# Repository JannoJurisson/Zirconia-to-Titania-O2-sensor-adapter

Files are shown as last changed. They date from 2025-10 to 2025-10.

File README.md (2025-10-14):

# Zirconia-to-Titania-O2-sensor-adapter
Adaper to translate a zirconia oxygen sensor voltage output (0-1V) to titania sensor signal (resistance or 0-5V)

Lambda_translator_top_no_screen

Lambda_translator_top_w_screen

Lambda_translator_bottom

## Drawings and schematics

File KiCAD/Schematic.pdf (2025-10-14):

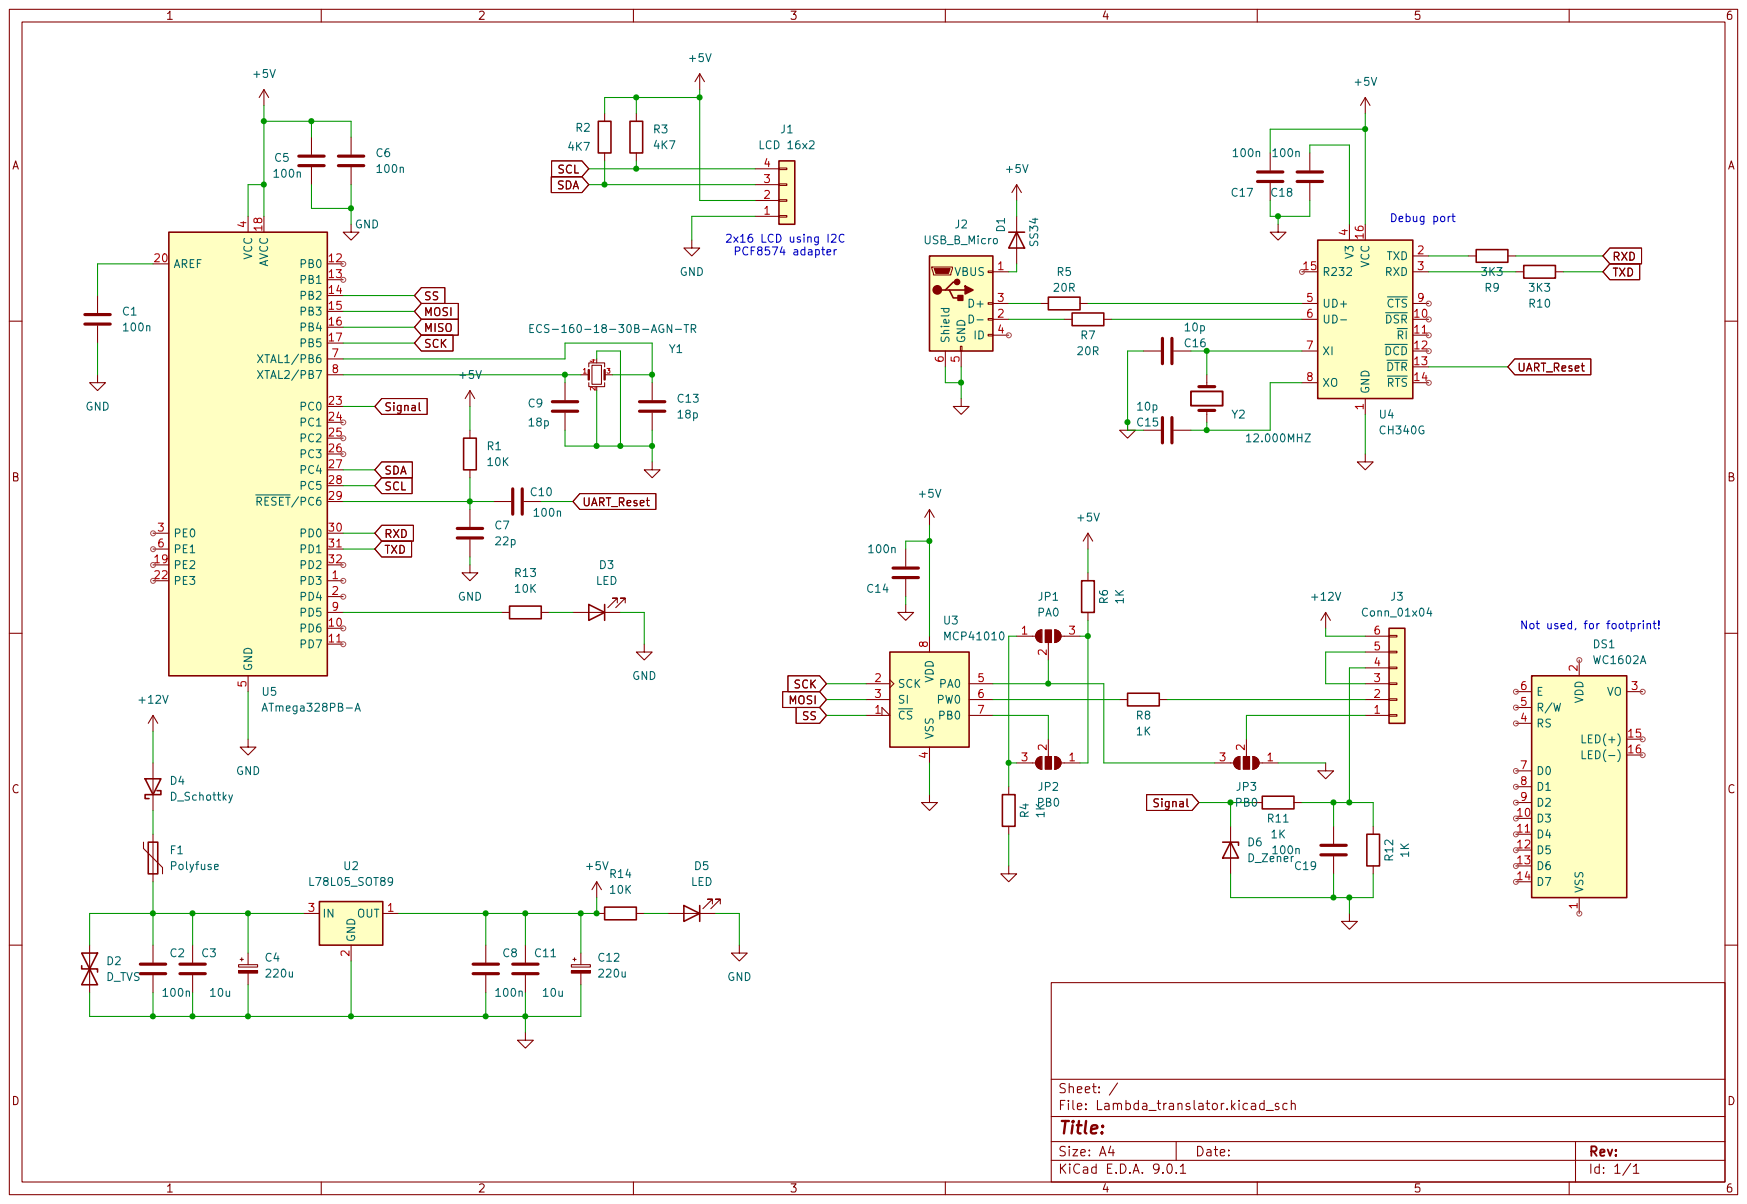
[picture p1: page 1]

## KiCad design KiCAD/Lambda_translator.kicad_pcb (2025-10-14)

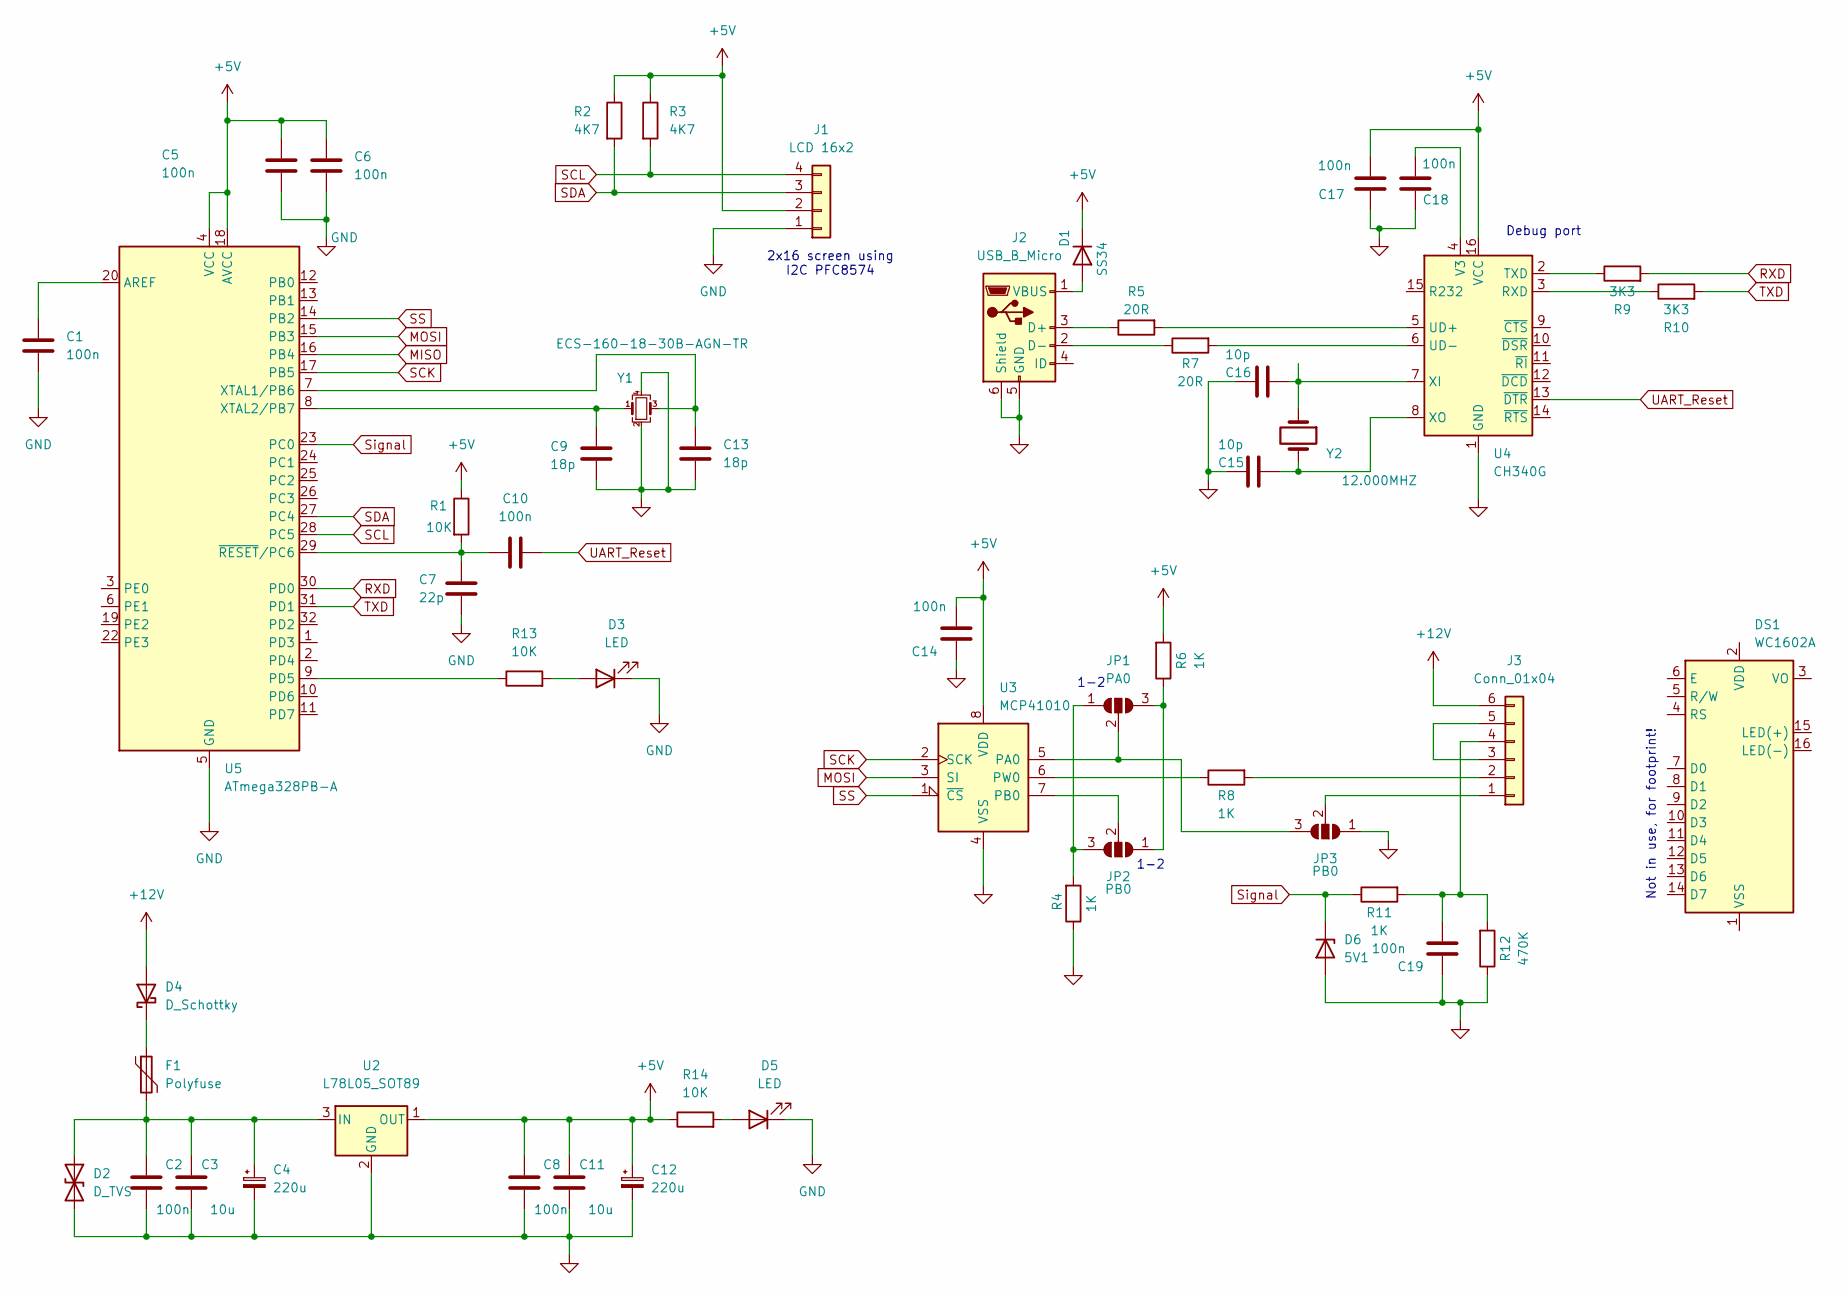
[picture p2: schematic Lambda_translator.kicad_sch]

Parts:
C1: 100n; R_0603_1608Metric
C2, C8, C14, C17, C18, C19: 100n; C_0603_1608Metric_Pad1.08x0.95mm_HandSolder
C3, C11: 10u; C_1206_3216Metric_Pad1.33x1.80mm_HandSolder
C4: 220u; CP_Elec_10x10
C5, C6, C10: 100n; C_0603_1608Metric
C7: 22p; C_0603_1608Metric
C9, C13: 18p; C_0805_2012Metric
C12: 220u; CP_Elec_6.3x5.9
C15, C16: 10p; C_0603_1608Metric_Pad1.08x0.95mm_HandSolder
D1: SS34; D_SMA
D2: D_TVS; D_SMA
D3, D5: LED; LED_1206_3216Metric
D4: D_Schottky; D_SMA
D6: 5V1; D_MiniMELF
DS1: WC1602A
F1: Polyfuse; R_2512_6332Metric
J1: LCD 16x2; PinHeader_1x04_P2.54mm_Vertical
J2: USB_B_Micro; USB_Micro-B_Molex_47346-0001
J3: Conn_01x04; PhoenixContact_MC_1,5_6-G-5.08_1x06_P5.08mm_Horizontal
JP1: PA0; SolderJumper-3_P1.3mm_Open_RoundedPad1.0x1.5mm
JP2, JP3: PB0; SolderJumper-3_P1.3mm_Open_RoundedPad1.0x1.5mm
R1, R13, R14: 10K; R_0603_1608Metric
R2, R3: 4K7; R_0603_1608Metric
R4, R6, R8, R11: 1K; R_0603_1608Metric_Pad0.98x0.95mm_HandSolder
R5, R7: 20R; R_0603_1608Metric_Pad0.98x0.95mm_HandSolder
R9, R10: 3K3; R_0603_1608Metric_Pad0.98x0.95mm_HandSolder
R12: 470K; R_0603_1608Metric_Pad0.98x0.95mm_HandSolder
U2: L78L05_SOT89; SOT-89-3
U3: MCP41010; SOIC-8_3.9x4.9mm_P1.27mm
U4: CH340G; SOIC-16_3.9x9.9mm_P1.27mm
U5: ATmega328PB-A; TQFP-32_7x7mm_P0.8mm
Y1: ECS-160-18-30B-AGN-TR; Crystal_SMD_Abracon_ABM3B-4Pin_5.0x3.2mm
Y2: 12.000MHZ; Crystal_SMD_5032-2Pin_5.0x3.2mm

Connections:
+5V: C5.2, C6.2, C8.1, C11.1, C12.1, C14.2, C17.2, D1.1 (K), J1.2, R1.1, R2.1, R3.1, R6.2, R14.1, U2.1 (OUT), U3.8 (VDD), U4.16 (VCC), U5.4 (VCC), U5.18 (AVCC)
+12V: D4.2 (A), J3.6
GND: C1.1, C2.2, C3.2, C4.2, C5.1, C6.1, C7.1, C8.2, C9.2, C11.2, C12.2, C13.2, C14.1, C15.2, C16.2, C17.1, C18.1, C19.1, D2.2 (A2), D3.1 (K), D5.1 (K), D6.2 (A), J1.1, J2.5 (GND), J2.6 (Shield), JP3.1 (A), R4.1, R12.1, U2.2 (GND), U3.4 (VSS), U4.1 (GND), U5.5 (GND), U5.21 (GND), Y1.2, Y1.4
MISO: U5.16 (PB4)
MOSI: U3.3 (SI), U5.15 (PB3)
unnamed: D1.2 (A), J2.1 (VBUS)
unnamed: C2.1, C3.1, C4.1, D2.1 (A1), F1.2, U2.3 (IN)
unnamed: D3.2 (A), R13.2
unnamed: D4.1 (K), F1.1
unnamed: D5.2 (A), R14.2
unnamed: J2.3 (D+), R5.1
unnamed: J2.2 (D-), R7.1
unnamed: J3.1, JP3.2 (C)
unnamed: J3.2, R8.2
unnamed: J3.3, J3.5
unnamed: C19.2, J3.4, R11.2, R12.2
unnamed: JP1.1 (A), JP2.3 (B), R4.2
unnamed: JP1.3 (B), JP2.1 (A), R6.1
unnamed: JP1.2 (C), JP3.3 (B), U3.5 (PA0)
unnamed: JP2.2 (C), U3.7 (PB0)
unnamed: R8.1, U3.6 (PW0)
unnamed: R10.1, U4.3 (RXD)
unnamed: R9.1, U4.2 (TXD)
unnamed: R5.2, U4.5 (UD+)
unnamed: R7.2, U4.6 (UD-)
unnamed: C18.2, U4.4 (V3)
unnamed: C16.1, U4.7 (XI), Y2.1
unnamed: C15.1, U4.8 (XO), Y2.2
unnamed: C1.2, U5.20 (AREF)
unnamed: R13.1, U5.9 (PD5)
unnamed: C13.1, U5.7 (XTAL1/PB6), Y1.3
unnamed: C9.1, U5.8 (XTAL2/PB7), Y1.1
unnamed: C7.2, C10.1, R1.2, U5.29 (~RESET/PC6)
RXD: R9.2, U5.30 (PD0)
SCK: U3.2 (SCK), U5.17 (PB5)
SCL: J1.4, R3.2, U5.28 (PC5)
SDA: J1.3, R2.2, U5.27 (PC4)
SS: U3.1 (~CS), U5.14 (PB2)
Signal: D6.1 (K), R11.1, U5.23 (PC0)
TXD: R10.2, U5.31 (PD1)
UART_Reset: C10.2, U4.13 (~DTR)

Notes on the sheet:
2x16 screen using I2C PFC8574
1-2
Not in use, for footprint!
Debug port

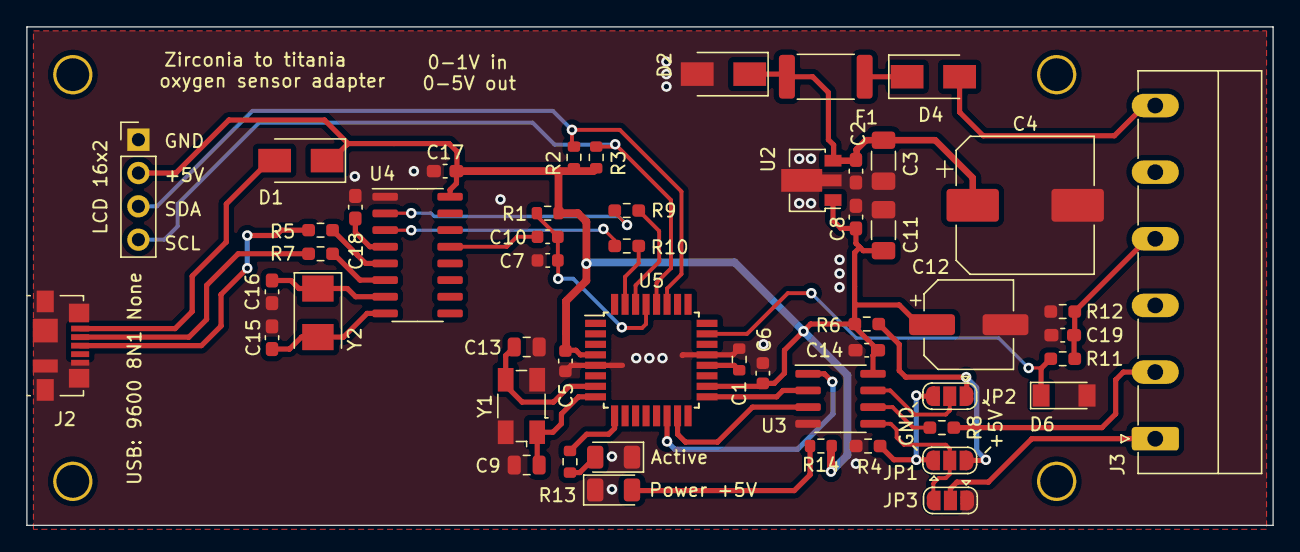
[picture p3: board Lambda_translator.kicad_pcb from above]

Board: 2 copper layers, 95.0 x 38.0 mm, 53 parts (0 on the bottom side), 40 nets.

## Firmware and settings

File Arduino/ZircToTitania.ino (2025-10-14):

#include <SPI.h>
#include <I2C.h>  // I2C libary with timeout
#include <MCP41_Simple.h>
#include <LiquidCrystal_I2C.h>
#include <avr/wdt.h>
#include <EEPROM.h>

LiquidCrystal_I2C lcd(0x3F, 16, 2);  // set the LCD address to 0x27 for a 16 chars and 2 line display

MCP41_Simple MyPot;

// ===== Tuning Parameters =====

// The maximum value for  digital potentiometer.
const float MAX_POT_VALUE = 255.0;
// The ADC value where the sharp transition should happen in raw ADC output
const float TRANSITION_POINT_ADC = 92.0;
// The steepness of the curve. Higher value = sharper transition.
const float STEEPNESS = 0.2;

int VoltageInPin = A0;
int InputADC = 0;
int potValue = 0;

int MainboardReset = 0;

unsigned long loopmillis = 0;
unsigned long measuremillis = 0;
const uint8_t CS_PIN = 10;

float voltage = 1.23;


void setup() {
  Serial.begin(9600);
  pinMode(5, OUTPUT);
  pinMode(VoltageInPin, INPUT);

  // Construct an instance of the MCP4XXX to manage the digipot.
  MyPot.begin(CS_PIN);

  MainboardReset = EEPROM.read(800);

  lcd.init();  // initialize the lcd
  lcd.backlight();

  Serial.println("------------------------------------------------------------------");
  Serial.println("--------Zirconia to Titania oxygen sensor signal converter--------");
  Serial.println("------------------------------------------------------------------");
  Serial.println();
  Serial.println();
  Serial.println("Zirconia sensor input : 0V-0.9V");
  Serial.println("Titania sensor resistance output : 1Kohm-100Kohm");
  Serial.println();

  MainboardReset++;
  if (MainboardReset == 255) {
    EEPROM.write(800, 0);
  }
  EEPROM.write(800, MainboardReset);
  Serial.print("Mainboard reset counter - ");
  Serial.println(MainboardReset);

  wdt_enable(WDTO_8S);  // enable watchdog


  //EEPROM.write(800, 0);
  //   pot->set(0);
}

void loop() {
  if (millis() - loopmillis >= 500) {

    digitalWrite(5, !digitalRead(5));  // Heartbeat LED
    loopmillis = millis();
    wdt_reset();
  }



  if (millis() - measuremillis >= 50) {
    InputADC = analogRead(VoltageInPin);



    Serial.print("ADC in =");
    Serial.println(InputADC);

    // ======== Create a 'bar' on LCD ==========
        if (InputADC > 192) {
      InputADC = 192;
    }
    int bar = InputADC / 12;

    for (int h = 0; h < bar; h++) {
      lcd.setCursor(h, 0);
      lcd.print("\xff");
    }
    for (int h = 15; h >= bar; h--) {
      lcd.setCursor(h, 0);
      lcd.print(" ");
    }

    lcd.setCursor(8, 1);
    lcd.print("V= ");
    lcd.setCursor(11, 1);
    lcd.print("   ");

    int adcValue = analogRead(VoltageInPin);
    voltage = adcValue * 44;
    voltage = voltage / 10000;

    lcd.setCursor(11, 1);
    lcd.print(voltage);


    Serial.print("Voltage in =");
    Serial.println(voltage);


    /*
    // logistic function formula to mimic narrowband Titania oxygen sensor signal 
    // the resistance should rise sharply after 14.7:1 A:F ratio (at ~0.45V from zirconia sensor)
    */
    float exponent = -STEEPNESS * (adcValue - TRANSITION_POINT_ADC);  
    float calculatedValue = MAX_POT_VALUE / (1.0 + exp(exponent));
    
    // ========== Constrain the potentiometer values
    int potValue = constrain((int)calculatedValue, 0, 255);

    MyPot.setWiper(potValue);  // set the new potentiometer value


    Serial.print("Pot value =");
    Serial.println(potValue);
    Serial.println("*********");

    lcd.setCursor(0, 1);
    lcd.print("P = ");
    lcd.setCursor(4, 1);
    lcd.print("   ");
    lcd.setCursor(4, 1);
    lcd.print(potValue);

    measuremillis = millis();
  }
}
